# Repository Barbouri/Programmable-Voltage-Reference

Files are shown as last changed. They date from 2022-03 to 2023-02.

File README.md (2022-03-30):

# Programmable-Voltage-Reference
An adjustable 0.001 to 5.000 volt reference, adjustable in 1 mV steps with display
==============================

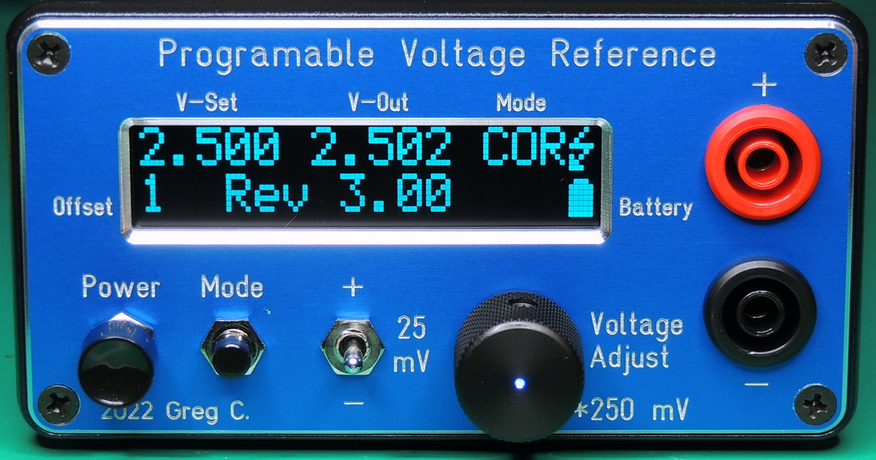
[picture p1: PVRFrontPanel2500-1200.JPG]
Programmable Voltage Reference with 1 mV resolution and 50 uV accuracy

This repository contains the design files and write-up for a Programmable Voltage Reference.  The reference has a range of 1 mV to 5.000 volts in 1 mV steps. The accuracy is plus or minus 50 uV for any set value. The reference value is displayed on a 2 X 16 character OLED display and can be set manually using the rotary encoder or remotely over the TTL serial to isolated USB 2.0 port.

The software folder contains an Arduino / Teensyduino sketch that is the source code for the voltage reference firmware.

Visit https://www.barbouri.com/2022/03/29/updating-the-programmable-voltage-reference-project/ for a more detailed explanation of the project design.

You can order this PCB directly from OSH Park.  Click on the following link.  
  * Programmable Voltage Reference V3.14- https://oshpark.com/shared_projects/pFu2IAUW

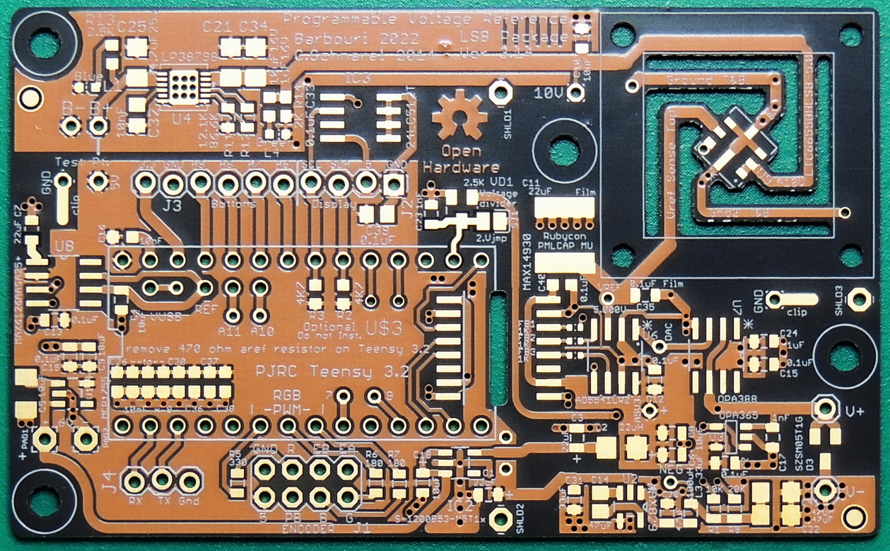
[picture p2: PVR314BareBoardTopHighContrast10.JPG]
PCB Top


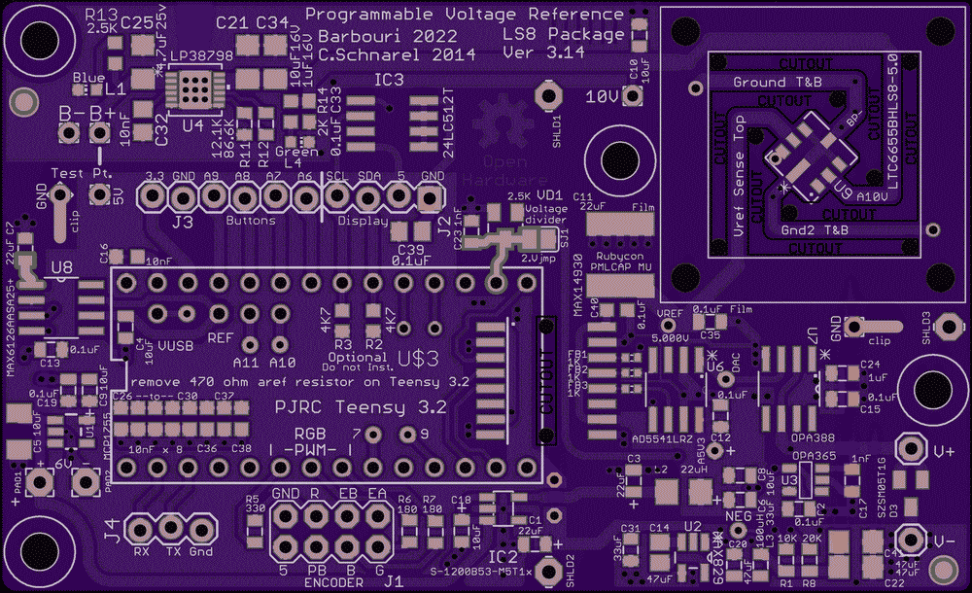
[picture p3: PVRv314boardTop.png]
Design Top


See the Bill of Materials (BOM) file in the repo Hardware folder for a parts list.  

## Status  
  * Version 3.14 PCB has been tested to be functional.
  * Version 3.15 PCB is untested with changes to silkscreen values and circuit trace widths.

## File Formats  

Hardware design files are in "CadSoft EAGLE PCB Design Software 7.7" .brd and .sch formats.  A free version of the software can be downloaded from https://www.autodesk.com/products/eagle/free-download.

The example code is in Arduino / Teensyduino .ino format (text).  A free version of the Arduino software can be downloaded from www.arduino.cc.
Teensyduino software add-on for the Arduino IDE can be downloaded from https://www.pjrc.com/teensy/teensyduino.html

Front panel was fabricated by "Front Panel Express" using "Front Panel Designer". A free version of the software can be downloaded from https://www.frontpanelexpress.com/front-panel-designer/download

## Distribution License  

Original design by C. Schnarel 2014 https://github.com/uChip/VoltageReferenceProgrammable

License:
<br /><span xmlns:dct="http://purl.org/dc/terms/" property="dct:title">Programmable Voltage Reference</span> by <a xmlns:cc="http://creativecommons.org/ns#" href="https://github.com/Barbouri/Programmable-Voltage-Reference" property="cc:attributionName" rel="cc:attributionURL">G. Christenson 2022 / C.Schnarel 2014</a> is licensed under a <a rel="license" href="http://creativecommons.org/licenses/by-sa/4.0/">Creative Commons Attribution-ShareAlike 4.0 International License</a>.

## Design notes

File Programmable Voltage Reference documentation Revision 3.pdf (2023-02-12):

Programmable Voltage Reference Command Set and Calibration for Revision 3.0 firmware

Serial interface set up: The PVR has an USB connector on the Teensy 3.2 that can be used for communication along with a serial communications header that interfaces with an isolated USB interface board. The protocol is standard UART at 115200-8-N-1. That is, 115200 baud, 8 data bits, no parity and one stop bit. All messages to and from the PVR are readable ASCII text. The messages can be sent or received / monitored by a terminal emulator program, however no line editing (backspace, etc.) is supported.

There is a 30 second delay at turn on to allow voltages and the reference to stabilize. The default mode at turn on is Corrected mode using calibration offsets, and an output voltage of 2.500 volts.
When the PVR powers up it sends out the message "Programmable Voltage Reference V3.0" followed by a carriage return character.
Anytime the PVR reference voltage is manually changed using the rotary encoder, button, toggle switch, or command the PVR sends out a serial communications message containing the new Set reference voltage value, Offset value, and measured Output voltage value, followed by a carriage return character.

Message format: All commands sent to the PVR should be in the form "CNNNN<nl>" (do not include the quotes) where:

C is a single character indicating the command to be done. Valid values are '#', '!', 'W', 'R', 'U','N',’C’,’O’. NNNN is four characters defining a decimal number. Each N is a digit character ('0' thru '9').

Together these form a number. The valid range for the number is defined in the context of the command.

<nl> (newline) is a single termination character. Valid values for <nl> are the carriage return character
( 0x0D ) or the linefeed character ( 0x0A ). If your terminal emulator sends both the extra will be ignored.

Command validation: If the message is less than six characters the message will be discarded. Beyond six characters will be ignored. If the message does not begin with one of the defined command characters the message will be discarded. If the message does not end with one of the <nl> characters the message will be discarded.

Note: Validation is NOT done on the N characters. Decimal conversion is done assuming each N is a valid digit character. If non-digit characters are given the decimal value will be generated based on their ASCII value.

Commands:

#: Sets the PVR reference value to NNNN millivolts, plus the internally stored calibration offset. The calibration offset value is displayed in the lower left Offset area of the OLED display. Only the bottom 13 bits of the reference value are used to program the DAC. A value of zero can be set with this command though the PVR may not actually output exactly zero volts. Values greater than 5000 will be treated as 5000. Front panel OLED displays COR for (corrected). The rotary dial LED is blue in this mode, and changes to violet if the output exceeds the error threshold. Default threshold is 5 mV.

!: Sets the PVR reference value to NNNN millivolts, without adding a calibration offset. Only the bottom 13 bits of the reference value are used to program the DAC. A value of zero can be set with this command though the PVR may not actually output exactly zero volts. Values greater than 5000 will be treated as 5000. The front panel OLED displays RAW, and the rotary dial LED is red in this mode.

W: Writes a value to onboard EEPROM memory. The previous set PVR reference value is used as the EEPROM address. The value to be written is created from NNNN. Only the lower 8 bits are used, therefore NNNN should be restricted to the range "0000" to "0255".
W0001<nl> would store an offset of +76.2 uV and W0255 would store an offset of -76.2 uV.

R: Returns the table of calibration offsets as a series of strings. Each string represents one onboard EEPROM memory location starting from zero. (Not Fully Implemented)
What I would like to implement is sending out a serial communications message with the address and offset value, starting at the current reference set value, and then send NNNN sequential address and offset pairs, and remain in the original mode when complete.

U: Sets an immediate global offset value to be used with the current reference value instead of using the offset from the calibration EEPROM memory. Similar to the W command, but isn’t stored in EEPROM, and is lost on reset or loss of power. Front panel OLED displays UOS in this mode and the rotary dial LED is green. The set global offset is displayed in the lower left Offset area of the OLED display.
For example sending U0002<nl> would set a global offset of +152.4 mV. Any changes to the set reference value using the front panel controls would include the global offset.

N: Returns Normal behavior from U command to look up offsets from the calibration memory and clear the global offset. For example sending N0000<nl> would perform the Return to normal behavior.

O: Turns off the OLED display while leaving the PVR and internal reference powered up. A valid # or ! command restores the OLED display. An example of the OLED off command is O0000<nl> .
Valid range for NNNN is 0000 to 5000 and the reference output is set to the value entered.

C: Front panel Calibration mode. Currently not implemented.
The original intent of the C (Calibrate) function is to put the PVR in a mode that allows the use of the front panel switch and rotary encoder to easily change the calibration offset using a connected calibrated meter on the output.

Instead of typing in offsets thru the USB port, the offset would be changed using the +/- 25 mV switch in 76.2 uV increments with real time changes shown on the calibrated meter, entered and stored using the rotary push-button, and then move on to the next setting using the rotary dial.

A nice addition would be to automatically use the last offset setting for the next output setting, and then just press the push-button to save if the output is within cal limits.

Typically the output stays within cal for many steps before needing to be changed, and then it typically only needs to change by one cal step.

Front Panel:

The front panel includes the 2 line by 16 character OLED display. The top line of the display shows the set reference voltage, the measured output voltage, mode, and charging indicator. The lower line of the display shows the calibration or global offset value, firmware revision, and battery status.

The power button turns on and off all power the unit including battery charging.

The mode button currently only resets the mode and set reference voltage to the default state.

The toggle switch increases or decreases the set reference voltage by 25 mV.

The rotary dial / pushbutton / LED, adjusts the set reference voltage up (clockwise) or down (counterclockwise) in 1 mV steps, pressing the dial pushbutton increases the set value by 250 mV per press until 5.000 volts is reached, and then cycles to 0.001 volts, as does the +/- 25 mV switch, and the rotary dial. The dial LED indicates the current mode and an output error condition.

The +/- reference output banana jacks accept both 4mm standard and safety sheathed banana plugs, and use a standard 0.75” spacing between jacks. The set reference output voltage is adjustable between 0.001 to 5.000 volts in 1 mV steps with a maximum output current of 15 mA.

Back Panel:

The back panel includes a 7.5 volt DC input barrel power jack which needs a minimum 5 watt supply.

The isolated micro USB connector is also located on the back panel and requires 5 volt power thru the connector to operate, which is typical for most USB cables.

Firmware:

The firmware was coded in Arduino 1.8.X and Teensyduino 1.56.
There are several variables in the firmware that set the initial defaults which may be changed:
refVal = 2500 | This sets the initial set reference voltage output to 2.500 volts.
errorvoltage = 5.0 | Maximum error difference between set and output voltage in mV.

oled.setBrightness(50) This sets the initial OLED display screen brightness. Range 0 to 255

delay(30000) | Initial 30 second delay on startup, minimum 5 seconds (5000)

Push button and toggle switch default values of 250 mV and 25 mV.

Additional to-do items:

Add Auto-calibration routine for calibration of Teensy ADC read back of actual output voltage.

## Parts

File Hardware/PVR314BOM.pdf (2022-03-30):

Part Value | Device | Package | Description | MFG | PN
C1 | 22uF | CAP_POL0805 | 0805-POL | Capacitor 22µF Molded Tantalum Polymer 10V 0805 200mOhm | KYOCERA AVX | F381A226MSA
C2 | 0.1uF | CAP0805 | 0805 | Capacitor ceramic bypass
C3 | 22uF | CAP_POL0805 | 0805-POL | Capacitor 22µF Molded Tantalum Polymer 10V 0805 200mOhm | KYOCERA AVX | F381A226MSA
C4 | 10uF | CAP0805 | 0805 | Capacitor
C5 | 10uF | CAP1206 | C1206K | Capacitor 10µF ±10% 16V Ceramic X7R 1206 | Kemet | C1206X105K4RACAUTO
C6 | 33uF | CAP_POL0805 | 0805-POL | Capacitor 33µF Molded Tantalum Polymer 10V 0805 200mOhm | KYOCERA AVX | F381A336MSALZT
C7 | 22uF | CAP0805 | 0805 | Capacitor
C8 | 10uF | CAP0805 | 0805 | Capacitor
C9 | 10uF | CAP_POL0805 | 0805-POL | Capacitor 10µF Molded Tantalum Polymer 10V 0805 200mOhm | KEMET | T529P106M010AAE200
C10 10uF | CAP0805 | 0805 | Capacitor
C11 22uF | CAP2220 | C2220K | Capacitor Film 22uF 20% 16VDC 2220 | Rubycon | 16MU226MD35750
C12 0.1uF | CAP0805 | 0805 | Capacitor ceramic bypass
C13 0.1uF | CAP0805 | 0805 | Capacitor ceramic bypass
C14 47uF | CAP0805 | C0805 | Capacitor 47µF ±20% 10V Ceramic X5R 0805 | KYOCERA AVX | 0805ZD476MAT2A
C15 0.1uF | CAP0805 | 0805 | Capacitor ceramic bypass
C16 10nF | CAP0603 | C0603K | Capacitor ceramic bypass
C17 1nF | CAP0805 | 0805 | Capacitor ceramic bypass C0G
C18 10uF | CAP_POL0805 | 0805-POL | Capacitor 10µF Molded Tantalum Polymer 10V 0805 200mOhm | KEMET | T529P106M010AAE200
C19 0.1uF | CAP0805 | 0805 | Capacitor ceramic bypass
C20 47uF | CAP0805 | 0805 | Capacitor
C21 10uF16V | CAP1206 | C1206 | Capacitor 10 µF ±10% 16V Ceramic X7R 1206 | Kemet | C1206X106K4RACAUTO
C22 47uF | CAPPOL1206 | 1206 | Capacitor Tantalum Polymer 6.3 V 1206 45mOhm | Vishay Spraque | T55A107M6R3C0045
C23 1nF | CAP0805 | 0805 | Capacitor
C24 1uF | CAP0805 | 0805 | Capacitor
C25 4.7uF25v | CAP1206 | C1206 | Capacitor
C26 10nF | CAP0603 | C0603K | Capacitor ceramic bypass
C27 10nF | CAP0603 | C0603K | Capacitor ceramic bypass
C28 10nF | CAP0603 | C0603K | Capacitor ceramic bypass
C29 10nF | CAP0603 | C0603K | Capacitor ceramic bypass
C30 10nF x 8 | CAP0603 | C0603K | Capacitor ceramic bypass
C31 33uF | CAP0805 | 0805 | Capacitor 33 µF Molded Tantalum Polymer 10V 0805 200mOhm | KYOCERA AVX | F381A336MSALZT
C32 10nF | CAP0805 | C0805 | Capacitor ceramic bypass
C33 0.1uF | CAP0603 | C0603 | Capacitor ceramic bypass

C34 1uF16V | CAP1206 | C1206 | Capacitor 1 µF ±10% 16V Ceramic X7R 1206 | Kemet | C1206X105K4RACAUTO
C35 0.1uF Film | CAP0805 | 0805 | Capacitor Film 0.1uF 20% 16VDC 2220 | Rubycon | 25MU104KZ22012
C36 10nF | CAP0603 | C0603K | Capacitor ceramic bypass
C37 10nF | CAP0603 | C0603K | Capacitor ceramic bypass
C38 10nF | CAP0603 | C0603K | Capacitor ceramic bypass
C39 0.1uF | CAP0805 | C0805 | Capacitor ceramic bypass
C40 0.1uF | CAP0603 | C0603 | Capacitor ceramic bypass
C41 47uF | CAPPOL1206 | 1206 | Capacitor Tantalum Polymer 6.3 V 1206 45mOhm | Vishay Spraque | T55A107M6R3C0045
D3 | SZSM05T1G | DIODE_CA-AC__ | SOT23C | 5V RS 9.8V Clamp 17A Ipp Tvs Diode Surface Mount SOT-23-3 | On Semiconductor | SZSM05T1G
FB1 1K | Ferrite Bead Inductor 0402 | Ferrite Bead Inductor 1 kOhms @ 100 MHz SMD 0402 | Murata | BLM15HG102SH1D
FB2 1K | Ferrite Bead Inductor 0402 | Ferrite Bead Inductor 1 kOhms @ 100 MHz SMD 0402 | Murata | BLM15HG102SH1D
FB3 1K | Ferrite Bead Inductor 0402 | Ferrite Bead Inductor 1 kOhms @ 100 MHz SMD 0402 | Murata | BLM15HG102SH1D
IC1 | MAX14930 | ISO7240 | SO-16DW | Digital Isolator 2750Vrms 4 Channel 25Mbps 16-SOIC-Wide | Analog Devices Inc./Maxim | MAX14930EAWE+
IC2 | S-1200B53-M5T1x MIC5219XX | SOT23-5 | IC REG LINEAR 5.3V 150MA SOT23-5 | ABLIC Inc. | S-1200B53-M5T1U
IC3 | 24LC64SN | SO8-EEPROM | SO-08 | Serial EEPROM 64/128/256/or 512K | MICROCHIP | 24LC64-I/SN
J1 | Encoder | M04X2 | 2X4 | 0.1" spacing Header, two rows of four | TE Connectivity AMP Connectors | 826656-4
J2 | Display | M04X1 | 1X04_LOCK | 0.1" spacing Header 4 part of 1X16 piece | TE Connectivity AMP Connectors | 1-825433-6
J3 | Buttons | M06X1 | 1X06_LOCK | 0.1" spacing Header 6 part of 1X16 piece | TE Connectivity AMP Connectors
J4 | Serial | M03X1 | 1X03_LOCK | 0.1" spacing Header 3 part of 1X16 piece | TE Connectivity AMP Connectors
H1T Teensy-R | M14X1 | 1X14 | Connector Header Through Hole 14 position 0.100" series 350 | Mill-Max Manufacturing Corp. | 350-10-114-00-006000
H1B Teensy-R | F14X1 | 1X14 | Connector Header Through Hole 14 position 0.100" series 350 | Mill-Max Manufacturing Corp. | 310-41-114-41-001000
H2T Teensy-L | M14X1 | 1X14 | Connector Header Through Hole 14 position 0.100" series 350 | Mill-Max Manufacturing Corp. | 350-10-114-00-006000
H2B Teensy-L | F14X1 | 1X14 | Connector Header Through Hole 14 position 0.100" series 350 | Mill-Max Manufacturing Corp. | 310-41-114-41-001000
H3T Teensy-I | M05X1 | 1X5 -1 | Connector Header Through Hole 5 position 0.100" Remove 1 pos | Mill-Max Manufacturing Corp. | 350-10-105-00-006000
H3B Teensy-I | F05X1 | 1X5 -1 | Connector Header Through Hole 5 position 0.100" Remove 1 pos | Mill-Max Manufacturing Corp. | 310-41-105-41-001000
L1 | Blue | 0603-LED | 0603 | LED Blue 0603 | Kingbright | APHM1608VRBXF/A-5
L2 | 22uH | 1210-IND | 1210 | INDUCTOR 22µH Shielded Wirewound 120mA 480mOhm Max | TDK Corporation | NLFV32T-220K-EF
L3 | 100uH | 0805-IND | 0805 | Inductors 100UH 50MA 4 OHM SMD | Taiyo Yuden | LBR2012T101KV
L4 | Green | 0603-LED | 0603 | LED Green 0603 | Vishay Semiconductor | VLMTG1300-GS08
R1 | 10K | 0805-RES | 0805 | Resistor 1% to 5%
R2 | 4.7K | 0603-RES | 0603 | Resistor Optional for testing - Do Not Install
R3 | 4.7K | 0603-RES | 0603 | Resistor Optional for testing - Do Not Install
R5 | 330 | 0805-RES | 0805 | Resistor 1% to 5%
R6 | 180 | 0805-RES | 0805 | Resistor 1% to 5%

R7 | 180 | 0805-RES | 0805 | Resistor 1% to 5%
R8 | 20K | 0805-RES | 0805 | Resistor 1% to 5%
R11 12.1K | 0805-RES | 0805 | Resistor ±0.1% 0.125W, 1/8W | Vishay Dale | TNPW080512K1BEEA
R12 86.6K | 0805-RES | 0805 | Resistor ±0.1% 0.125W, 1/8W | Vishay Dale | TNPW080580K6BEEN
R13 2.5K | 0603-RES | 0603 | Resistor 1% to 5%
R14 2K | 0603-RES | 0603 | Resistor 1% to 5%
U$3 PJRC Teensy 3.2 | TEENSY_3.1_DIL+4 | TEENSY-DIL+4 Teensy 3.1 and 3.2 in a DIL package with the inner 4 pins
U1 | MCP1755 | V_REG_LDOSMD | SOT-23-5 | IC REG LINEAR 5V 300MA SOT23-5 LDO | Microchip Technology | MCP1755T-5002E/OT
U2 | MAX829 | MAX829EUK+T | SOT-23-5 | Switched-Capacitor Voltage Inverters | Maxim | MAX829EUK+T
U3 | OPA365 | OPA365 | SOT-23-5 | General Purpose Amplifier 1 Circuit Rail-to-Rail SOT-23-5 | Texas Instruments | OPA365AIDBVR
U4 | LP38798 | LP38798SD-ADJ | DNT12 | | Texas Instruments | LP38798SD-ADJ/NOPB
U6 | AD5541LRZ | AD5541LRZ | SOIC-8 | 16-Bit Digital-to-Analog Converters | Analog Devices | AD5541LRZ
U7 | OPA388 | LTC2050IS8PBF | SOIC-8 | Zero-Drift Operational Amplifi ers | Linear Technology | OPA388
U8 | MAX6126AASA25+ Voltage Reference | SOIC-8 | Series, Buried Zener Reference. Fixed 2.5V 0.04% 15mA 8-SOIC | Analog Devices Inc./Maxim | MAX6225ACSA+
U9 | LTC6655BHLS8-5.0 Voltage Reference | LCC-8_LS8 | Series Voltage Ref. IC Fixed 5V 0.025% 5 mA 8-CLCC | Linear Technology | LTC6655BHLS8-5.000
VD1 2.5K-2.5K | LM50 | SOT-23 | SOT-23 Voltage Divider

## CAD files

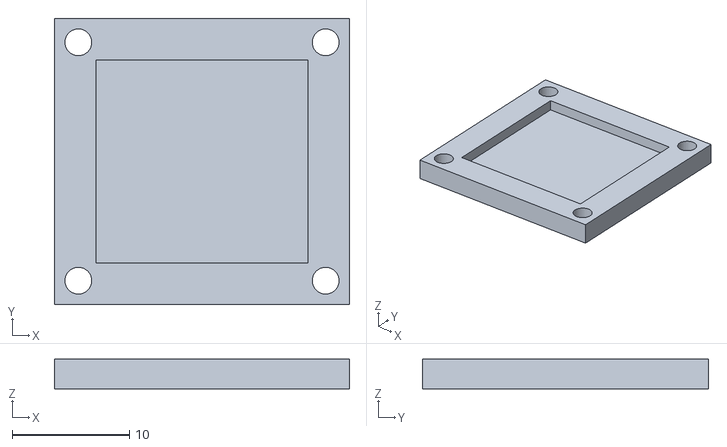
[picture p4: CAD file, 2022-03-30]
Hardware/3DcoversSTL/Bottom_Cover1_v1.stl
25.1 x 24.4 x 2.54

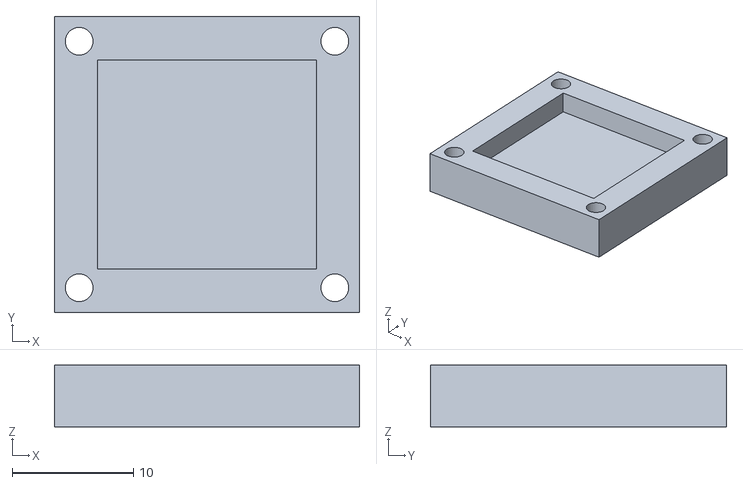
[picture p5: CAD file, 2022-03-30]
Hardware/3DcoversSTL/Top_Cover1_v1.stl
25.1 x 24.4 x 5.08

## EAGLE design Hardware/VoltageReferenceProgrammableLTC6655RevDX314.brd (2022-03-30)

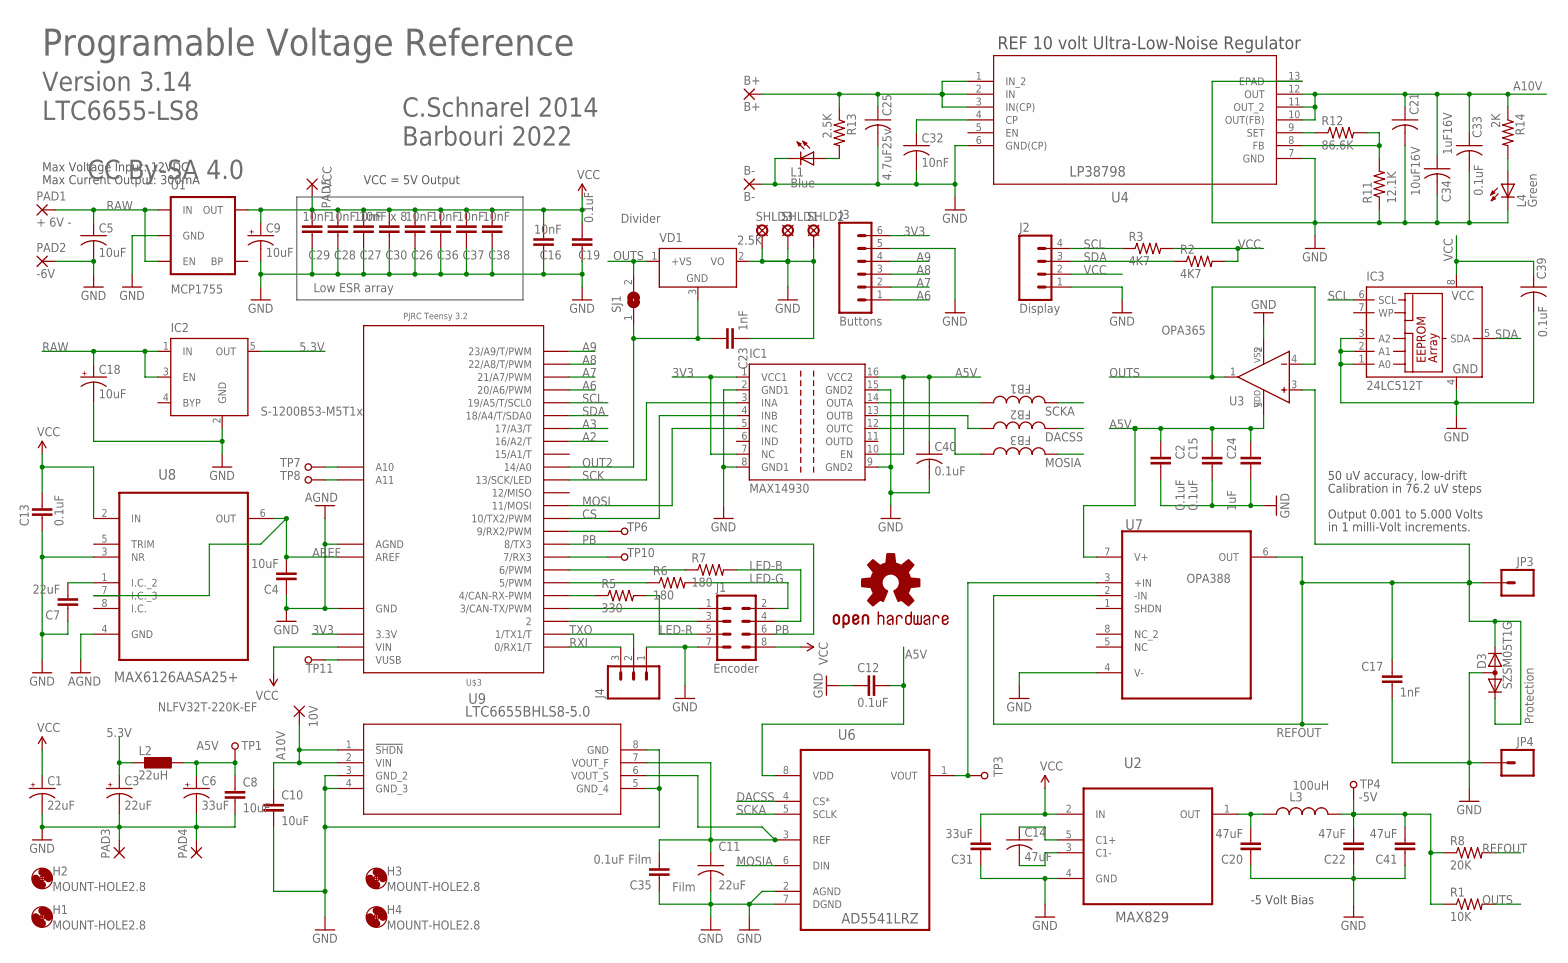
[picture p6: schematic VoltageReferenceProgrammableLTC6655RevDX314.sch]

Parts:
10V: 1,6/0,9
B+: B+; 1,6/0,9
B-: B-; 1,6/0,9
C1, C3: 22uF; 0805-POL
C2, C12, C13, C15, C19: 0.1uF; 0805
C4, C8, C10: 10uF; 0805
C5: 10uF; C1206K
C6: 33uF; 0805-POL
C7: 22uF; 0805
C9, C18: 10uF; 0805-POL
C11: 22uF; C2220K
C14: 47uF; C0805
C16, C26, C27, C28, C29, C36, C37, C38: 10nF; C0603K
C17, C23: 1nF; 0805
C20: 47uF; 0805
C21: 10uF16V; C1206
C22, C41: 47uF; 1206
C24: 1uF; 0805
C25: 4.7uF25v; C1206
C30: 10nF x 8; C0603K
C31: 33uF; 0805
C32: 10nF; C0805
C33, C40: 0.1uF; C0603
C34: 1uF16V; C1206
C35: 0.1uF Film; 0805
C39: 0.1uF; C0805
D3: SZSM05T1G; SOT23C
FB1, FB2, FB3: 1K; WE-CBA_0402(W=1.5)
H1, H2, H3, H4: MOUNT-HOLE2.8; 2,8
IC1: MAX14930; SO-16DW
IC2: S-1200B53-M5T1x; SOT23-5
IC3: 24LC512T; SO-08
J1: Encoder; 2X4
J2: Display; 1X04_LOCK
J3: Buttons; 1X06_LOCK
J4: M03LOCK; 1X03_LOCK
JP3, JP4: M01PTH; 1X01
L1: Blue; CHIP-LED0603
L2: 22uH; L3225P
L3: 100uH; 0805
L4: Green; CHIP-LED0603
LOGO1: OSHW-LOGOM; OSHW-LOGO-M
PAD1: + 6V -; 2,15/1,0
PAD2: -6V; 2,15/1,0
PAD3, PAD4, PAD5: 1,6/0,9
R1: 10K; 0805
R2, R3: 4K7; R0603
R5: 330; 0805
R6, R7: 180; 0805
R8: 20K; 0805
R11: 12.1K; 0805
R12: 86.6K; 0805
R13: 2.5K; R0603
R14: 2K; R0603
SHLD1, SHLD3: SHLD1; LSP11
SHLD2: SHLD2; LSP11
SJ1: SJ
TP1, TP3, TP4, TP6, TP7, TP8, TP10, TP11: TEST_POINT; BBD-VIA
U1: MCP1755; SOT23-5
U2: MAX829; SOT95P280X145-5N
U3: OPA365; SOT-23-5
U4: LP38798; DNT12
U6: AD5541LRZ; SOIC127P600X175-8N
U7: OPA388; SOIC127P600X175-8N; MPN OPA388
U8: MAX6126AASA25+; SOIC127P600X175-8N
U9: LTC6655BHLS8-5.0; LCC-8_LS8
U$3: PJRC Teensy 3.2; TEENSY3-DIL+4
VD1: 2.5K; SOT23

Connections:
3V3: IC1.1 (VCC1), IC1.7 (NC), J3.6, U$3.3.3V
5.3V: C3.1 (+), IC2.5 (OUT), L2.2
9: TP6.P$1, U$3.9 (9/RX2/PWM)
-5V: C22.2, C41.2, L3.2, R1.1, R8.1, TP4.P$1
A2: U$3.16/A2 (16/A2/T)
A3: U$3.17/A3 (17/A3/T)
A5V: C2.1, C6.1 (+), C8.1, C12.1, C15.1, C24.1, C40.1, IC1.10 (EN), IC1.16 (VCC2), L2.1, TP1.P$1, U3.5 (VDD), U6.8 (VDD), U7.7 (V+)
A6: J3.1, U$3.20/A6 (20/A6/PWM)
A7: J3.2, U$3.21/A7 (21/A7/PWM)
A8: J3.3, U$3.22/A8 (22/A8/T/PWM)
A9: J3.4, U$3.23/A9 (23/A9/T/PWM)
A10V: 10V.1, C10.1, C21.1, C33.1, C34.1, R14.1, U4.10 (OUT(FB)), U4.11 (OUT_2), U4.12 (OUT), U9.1 (!SHDN), U9.2 (VIN)
AGND: U8.4 (GND)
AREF: C4.2, U8.6 (OUT), U8.7 (I.C._3), U$3.AREF
BATT: B+.1, C25.1, R13.1, U4.1 (IN_2), U4.2 (IN), U4.3 (IN(CP))
CS: IC1.4 (INB), U$3.10 (10/TX2/PWM)
DACSS: FB2.2, U6.4 (CS*)
EA: J1.1, U$3.3 (3/CAN-TX/PWM)
EB: J1.3, U$3.2
GND: B-.1, C1.2 (-), C2.2, C3.2 (-), C4.1, C5.2, C6.2 (-), C7.1, C8.2, C9.2 (-), C10.2, C11.2, C12.2, C13.2, C15.2, C16.1, C17.1, C18.2 (-), C19.1, C20.1, C21.2, C22.1, C23.1, C24.2, C25.2, C26.1, C27.1, C28.1, C29.1, C30.1, C31.1, C32.2, C33.2, C34.2, C35.1, C36.1, C37.1, C38.1, C39.2, C40.2, C41.1, D3.3 (A), IC1.2 (GND1), IC1.8 (GND1), IC1.9 (GND2), IC1.15 (GND2), IC2.2 (GND), IC3.1 (A0), IC3.2 (A1), IC3.3 (A2), IC3.4 (GND), J1.7, J2.1, J3.5, J4.1, JP4.1, L1.C, L4.C, PAD2.1, PAD3.1, PAD4.1, R11.1, SHLD1.MP, SHLD2.MP, SHLD3.MP, U1.2 (GND), U2.4 (GND), U3.2 (VSS), U4.6 (GND(CP)), U4.7 (GND), U4.13 (EPAD), U6.2 (AGND), U6.7 (DGND), U7.4 (V-), U8.3 (NR), U9.3 (GND_2), U9.4 (GND_3), U9.5 (GND_4), U9.8 (GND), U$3.AGND, U$3.GND, VD1.2 (VO)
LED-B: J1.4, R7.2
LED-G: J1.2, R6.2
LED-R: J1.5, R5.2
MOSI: IC1.5 (INC), U$3.11 (11/MOSI)
MOSIA: FB3.2, U6.6 (DIN)
unnamed: R12.1, U4.9 (SET)
unnamed: C7.2, U8.1 (I.C._2)
unnamed: R5.1, U$3.4 (4/CAN-RX-PWM)
unnamed: R6.1, U$3.5 (5/PWM)
unnamed: R7.1, U$3.6 (6/PWM)
unnamed: TP3.P$1, U6.1 (VOUT), U7.3 (+IN)
unnamed: TP7.P$1, U$3.A10
unnamed: C20.2, L3.1, U2.1 (OUT)
unnamed: TP8.P$1, U$3.A11
unnamed: R11.2, R12.2, U4.8 (FB)
unnamed: TP10.P$1, U$3.7 (7/RX3)
unnamed: TP11.P$1, U$3.VUSB
unnamed: C14.2, U2.3 (C1-)
unnamed: C32.1, U4.4 (CP)
unnamed: C14.1, U2.5 (C1+)
unnamed: FB1.1, IC1.14 (OUTA)
unnamed: L1.A, R13.2
unnamed: FB2.1, IC1.13 (OUTB)
unnamed: FB3.1, IC1.12 (OUTC)
unnamed: L4.A, R14.2
OUT2: C23.2, SJ1.1, U$3.14/A0, VD1.3 (GND)
OUTS: R1.2, SJ1.2, U3.1 (OUT), U3.4 (IN-), VD1.1 (+VS)
PB: J1.6, U$3.8 (8/TX3)
RAW: C5.1, C18.1 (+), IC2.1 (IN), IC2.3 (EN), PAD1.1, U1.1 (IN), U1.3 (EN)
REFOUT: C17.2, D3.1 (K1), D3.2 (K2), JP3.1, R8.2, U3.3 (IN+), U7.2 (-IN), U7.6 (OUT)
RXI: J4.3, U$3.0 (0/RX1/T)
SCK: IC1.3 (INA), U$3.13 (13/SCK/LED)
SCKA: FB1.2, U6.5 (SCLK)
SCL: IC3.6 (SCL), J2.4, R3.1, U$3.19/A5 (19/A5/T/SCL0)
SDA: IC3.5 (SDA), J2.3, R2.1, U$3.18/A4 (18/A4/T/SDA0)
TXO: J4.2, U$3.1 (1/TX1/T)
VCC: C1.1 (+), C9.1 (+), C13.1, C16.2, C19.2, C26.2, C27.2, C28.2, C29.2, C30.2, C31.2, C36.2, C37.2, C38.2, C39.1, IC3.8 (VCC), J1.8, J2.2, PAD5.1, R2.2, R3.2, U1.5 (OUT), U2.2 (IN), U8.2 (IN), U$3.VIN
VREF: C11.1, C35.2, U6.3 (REF), U9.6 (VOUT_S), U9.7 (VOUT_F)

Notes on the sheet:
Max Voltage Input: 12VDC
Max Current Output: 300mA
VCC = 5V Output
Programable Voltage Reference
Version 3.14 LTC6655-LS8
Output 0.001 to 5.000 Volts
in 1 milli-Volt increments.
50 uV accuracy, low-drift
Calibration in 76.2 uV steps
C.Schnarel 2014 Barbouri 2022
Protection
Divider
Low ESR array
CC By-SA 4.0
REF 10 volt Ultra-Low-Noise Regulator
-5 Volt Bias

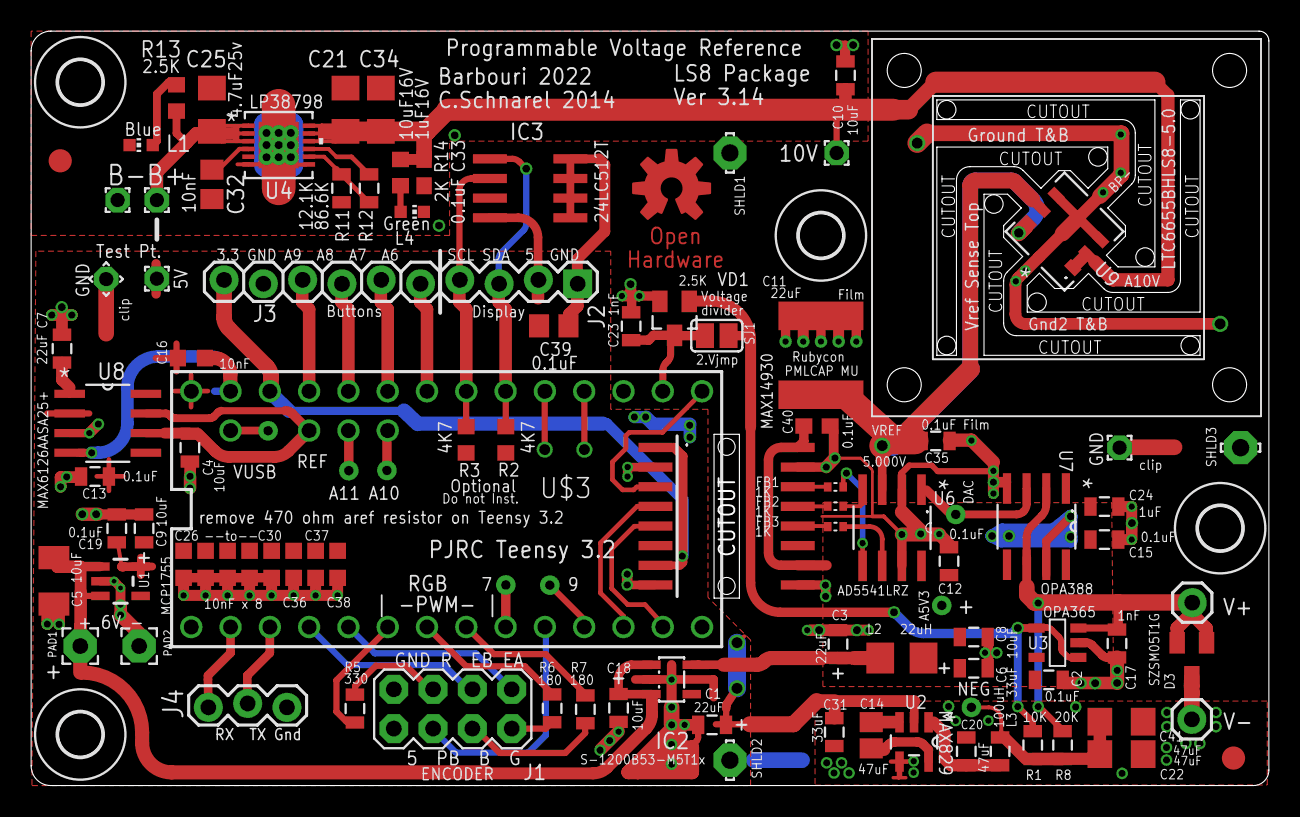
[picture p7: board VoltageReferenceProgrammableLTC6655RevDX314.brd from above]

Board: 2 copper layers, 80.0 x 48.8 mm, 107 parts (1 on the bottom side), 55 nets.

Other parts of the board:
FID1: 1; FIDUCIAL_G15
FID2: 2; FIDUCIAL_G15
U$1: OSHW-LOGO-M_COPPER

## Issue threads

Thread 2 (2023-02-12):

Feature - Add Auto-calibration routine for Teensy ADC

Barbouri, 2023-02-12:
Add Auto-calibration routine for calibration of Teensy ADC read back of actual output voltage.
Assign command code "A" and require confirmation to proceed using Mode button.

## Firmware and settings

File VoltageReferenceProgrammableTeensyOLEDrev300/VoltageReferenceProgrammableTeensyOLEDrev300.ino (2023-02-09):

/* Programmable Voltage Reference V3.00
For use with Barbouri - Programmable Voltage Reference V3.15 - V3.16 circuit boards
2014 uChip (C. Schnarel) Original software for RevD boards
2017 Barbouri (G. Christenson) Modified for Teensy 3.2 based board with I2C LED display
http://www.barbouri.com/2016/07/21/programmable-voltage-reference-v2-12-assembly/
CC BY-SA 4.0 US
12 September 2017 added +/-50mv buttons on pins 21, 22
   added Mode reset switch on pin 20 for CORRECTED mode and 1.000V
   added Power switch on pin 23 to disable LTC1152 and place it in tri-state mode,
   clear LED display (blank), and set LEDcolor to black. Teensy and references
   remain powered. After switching power switch on, Mode reset must be pressed.
   added averaging for Teensy A0 input voltage monitoring, and additional calibration
   variables to compensate for Teensy A-D errors

Modified for V2.25 board - LTC1152 enable, onboard -5 supply, serial & button headers

January 2022 - major update for hardware version 3.14/3.15 5.000 volt PVR
  see blog post for more information - https://www.barbouri.com/2022/03/29/updating-the-programmable-voltage-reference-project/
  
Include libraries this sketch will use
*/
#include <SPI.h>                  // part of Arduino - Teensyduino distribution
#include <EEPROM.h>               // part of Arduino - Teensyduino distribution
#include <JC_EEPROM.h>            // https://github.com/JChristensen/JC_EEPROM
#include <Rotary.h>               // https://github.com/brianlow/Rotary
#include <Bounce2.h>              // http://playground.arduino.cc/Code/Bounce
#include <Wire.h>                 // part of Arduino - Teensyduino distribution
#include <avr/io.h>
#include <avr/interrupt.h>        // AVR interrupt header
#include "I2cCharDisplay.h"       // https://github.com/dcityorg/i2c-char-display-library-arduino
#include <Adafruit_MCP23017.h>    // Adafruit IO expander wothout display
// #include <Adafruit_RGBLCDShield.h>   // include MODIFIED Adafruit RGB I2C Display to include 6th MENU button
// #include "Adafruit_LEDBackpack.h" // https://github.com/adafruit/Adafruit_LED_Backpack
// #include "Adafruit_GFX.h"         // https://github.com/adafruit/Adafruit-GFX-Library

// Defines
#define OLEDADDRESS    0x3c       // i2c address for the oled display
I2cCharDisplay oled(OLED_TYPE, OLEDADDRESS, 2); // create an oled object for a 2 line display

// Create a set of new symbols that can be displayed on the LCD
byte batt_full[8] = {B01110,B11111,B11111,B11111,B11111,B11111,B11111,B11111};      // full battery, 9.0V
byte batt_8_7[8] = {B00000,B01110,B11111,B11111,B11111,B11111,B11111,B11111};       // 8.7V level
byte batt_8_3[8] = {B00000,B00000,B01110,B11111,B11111,B11111,B11111,B11111};       // 8.3V level
byte batt_8_0[8] = {B00000,B00000,B00000,B01110,B11111,B11111,B11111,B11111};       // 8.0V level
byte batt_7_7[8] = {B00000,B00000,B00000,B00000,B01110,B11111,B11111,B11111};       // 7.7V level
byte batt_7_5[8] = {B00000,B00000,B00000,B00000,B00000,B01110,B11111,B11111};       // 7.5V level
byte batt_empty[8] = {B00100,B00100,B00100,B00000,B00100,B00000,B01110,B11111};     // <7.3V Empty
byte batt_charging[8] = {B00010,B00100,B01000,B11111,B00010,B10100,B11000,B11100};  // >10V Charging symbol

// DAC Slave Select
#define DACSS 10

// Mode values
#define CORRECTED true  // send refVal to DAC after adding correction factor
#define RAW false       // send raw refVal numbers to the DAC w/o correcting

// RGB Rotary encoder LED's
#define redled 4
#define greenled 5
#define blueled 6

// LTC1152 enable output to MAX14930 isolator pin 6 input, pin 11 output to LTC1152
#define outputena 9

// Instantiate Rotary encoder object
Rotary r = Rotary(2, 3);
// Instantiate Bounce objects
Bounce bp = Bounce();
Bounce bu = Bounce();
Bounce bd = Bounce();
Bounce bm = Bounce();

// Setup JC_EEPROM values for 24LC512T IC1
JC_EEPROM eep(JC_EEPROM::kbits_512, 2, 64);      //one 24LC512 EEPROM on the bus - device size, number of devices, page size
  
// Instantiate objects used in this project
int16_t MAXVAL = 5000;    // DAC Maximum value
int16_t MINVAL = 1;        // DAC Minimum value

// LED colors used in LEDcolor()
uint8_t red = 0x1;
uint8_t yellow = 0x3;
uint8_t green = 0x2;
uint8_t teal = 0x6;
uint8_t blue = 0x4;
uint8_t violet = 0x5;
uint8_t white = 0x7;
uint8_t black = 0x0;

int DispBCD = 0;
int analog0 = A0;           // Analog input pin on Teensy 3.2
int code = 0;
int color = 0;
uint32_t i = 0;
int8_t offset = 0;
int16_t refVal = 2500;      // Initial voltage output setting 2.500 volt
float num = refVal;
uint32_t Addr = 0;
uint8_t CmdArray[7];
uint8_t CmdArrayIdx = 0;
uint8_t sdata;
uint16_t DACreg;
boolean newVal = true;
boolean mode = CORRECTED;   // when mode = CORRECTED then offset value is used
boolean useFlag = false;    // when true uses downloaded value of offset
// boolean PWR = true;         // Power switch
float errorvoltage = 5.0;   // Maximum difference between set and output voltage
float average = 0.0000;     // the average for A0 read


//-=|=-=|=-=|=-=|=-=|=-=|=-=|=-=|=-=|=-=|=-=|=-=|=-=|=-=|=-=|=-=|
void setup() {
  // Initialize USB interface
  Serial1.begin(115200);
  r.begin(false);
  delay(250);
  Serial1.println("Programmable Voltage Reference V3.00");

  oled.begin();             // initialize the oled

  // Load battery symbols to OLED memory
    oled.createCharacter(0, batt_full);
    oled.createCharacter(1, batt_8_7);
    oled.createCharacter(2, batt_8_3);
    oled.createCharacter(3, batt_8_0);
    oled.createCharacter(4, batt_7_7);
    oled.createCharacter(5, batt_7_5);
    oled.createCharacter(6, batt_empty);
    oled.createCharacter(7, batt_charging);

  // Setup initial OLED display screen
    oled.setBrightness(50);
    oled.clear();
    oled.cursorMove(1, 1);
    oled.print("0.000 0.000 COR");
    oled.cursorMove(1, 16);
    oled.write(7);
    oled.cursorMove(2, 16);
    oled.write(1);
    oled.cursorMove(2, 1);
    oled.print("Rev 3.0 Delay30");
  delay(30000);
    oled.cursorMove(2, 1);
    oled.print("   Rev 3.00    ");
    
  //---- initialize the i2c/MCP23017 library
  Adafruit_MCP23017 mcp;
 
  pinMode(redled, OUTPUT);
  pinMode(greenled, OUTPUT);
  pinMode(blueled, OUTPUT);
  pinMode(outputena, OUTPUT);
  digitalWrite(outputena, HIGH);
  
  LEDcolor(blue);           // Set initial LED color
  mcp.begin();      // use default address 0
  // lcd.setBacklight(BLUE);   // set I2C RGB LED color to Blue

  byte i2cStat = eep.begin(JC_EEPROM::twiClock400kHz);
    if ( i2cStat != 0 ) {
      Serial1.print ("EEPROM setup problem");  //there was a problem
    }

  // Initialize EEPROM to 0's *****************************
  // Run once to set all MAXVAL memory values to 0 by uncommenting
  // the next three lines, and running once on the Teensy 3.2, then recomment.
  // for(i=0;i<MAXVAL;i++){
  //     eep.write(i, 0);  
  //   }

  // Calibrate Teensy ADC to Output value
  // for(i=6000;i<11000;i++){
  //     eep.write(i, 0);  
  //   }

  // Attach buttons with de-bounce using "Bounce2"
  bp.attach(8, INPUT);
  bp.interval(5);
  bu.attach(22,INPUT_PULLUP);
  bu.interval(5);
  bd.attach(21, INPUT_PULLUP);
  bd.interval(5);
  bm.attach(23, INPUT_PULLUP);
  bm.interval(5);
  
  bp.update();          // Check if Rotary encoder button is held On, on power-up
  if(bp.read() == HIGH) {
    mode = RAW;             // If button is held-On set RAW mode
    LEDcolor(red);
    }
    else {
    mode = CORRECTED;       // If button is Off set normal CORRECTED mode
    LEDcolor(blue);
    }
 
  // Setup A-D converter on Teensy 3.2 to use external 2.048 reference and 14 bits
  analogReference(EXTERNAL);
  analogReadResolution(14);
  analogReadAveraging(32);
  
  // set up the select control pin for the DAC
  // DAC select is active low, data is shifted in MSB first
  // on the falling edge of the clock
  pinMode(DACSS, OUTPUT);
  digitalWrite(DACSS, HIGH);
  SPI.begin();
  SPI.setDataMode(SPI_MODE1);  // set to falling edge clock
  SPI.setBitOrder(MSBFIRST);  // set to MSB first
}

// =-=|=-=|=-=|=-=|=-=|=-=|=-=|=-=|=-=|=-=|=-=|=-=|=-=|=-=|=-=|=-=|
void loop() {
  
  // Increment by 500 if the rotary encoder button was pressed
  // If the increment result is more than MAX just set result to zero
  if(bp.update()) {
    if(bp.read() == HIGH) {
      refVal+=250;
      if(refVal>MAXVAL)refVal=1;
      newVal = true;
    }
  }

  // Increment by 50 if the panel 50mv + button was pressed
  // If the increment result is more than MAX just set result to zero
  if(bu.update()) {
    if(bu.read() == HIGH) {
      refVal+=25;
      if(refVal>MAXVAL)refVal=1;
      newVal = true;
    }
  }
  
  // Decrement by 50 if the panel 50mv - button was pressed
  // If the decrement result is less than MIN just set result to zero
  if(bd.update()) {
    if(bd.read() == HIGH) {
      refVal-=25;
      if(refVal<MINVAL)refVal=1;
      newVal = true;
    }
  }

  // Reset to CORRECTED mode if the panel Mode - button was pressed
  // Set Output to 1.000 V and enable LTC1152 output
  
  if(bm.update()) {
    if(bm.read() == HIGH) {
    mode = CORRECTED;
    LEDcolor(blue);
    refVal = 2500;
    newVal = true;
    }
  }

  // Check the rotary encoder and increment or decrement if it was turned
  // If the increment result is more than MAX roll over to zero
  // If the decrement goes below zero value will roll over to 65535 (unsigned word)
  // In that case set to result to MAX value
  unsigned char result = r.process();
  if (result) {
    result == DIR_CW ? refVal-- : refVal++;
    if(refVal<1)refVal=MAXVAL;
    if(refVal>MAXVAL)refVal=1;
    newVal = true;
  }

  while (Serial1.available())  // Read command from Teensy USB connection
                              // requires mode character, 4 numeric digits, then
                              // LineFeed or CarrigeReturn or both
                              // valid mode charactors: # ! W R U N O C
  {
    sdata = Serial1.read();
    switch (sdata){
    case 35: // '#'  set DAC with correction factor
    case 33: // '!'  set DAC with no correction factor
    case 'W': // 'W' write offset values to EEPROM
    case 'R': // 'R' dump the offset table (mostly for debug)
    case 'U': // 'U' use a temporary offset (must be in CORRECTED mode to use)
    case 'N': // 'N' clear temporary offset and use correction factor
    case 'O': // 'O' turn Off OLED and set DAC with correction factor
    case 'C': // 'C' set calibration mode with no correction factor
      CmdArrayIdx = 0;
      CmdArray[CmdArrayIdx++] = sdata;
      break;
    case 10: // LF
    case 13: // CR
      CmdArray[CmdArrayIdx++] = sdata;
      if(ParseCommand())
        newVal = true;
      break;
    default:
      CmdArray[CmdArrayIdx++] = sdata;
      if(CmdArrayIdx>6) CmdArrayIdx = 6;
    }
  }  

  // If the value has changed, update the display and send 
  // the new value to the DAC and the serial port
  if(newVal) {
    Serial1.print("Set voltage = ");
    Serial1.print((float)refVal/1000, 3);
        
    // Convert the 12-bit DAC value into a 16-bit value plus
    // an optional signed 8-bit correction factor.
    
    // First look up the correction factor
    if(!useFlag){
      offset = eep.read(refVal);
    }
    
    // Next shift the 12-bit value up 4 bits and add in the correction factor if desired.
    if(mode == CORRECTED) {
     Serial1.print(" Offset = ");
     Serial1.print(offset);
     oled.cursorMove(2, 1);
     oled.print("   ");        // clear offset on line 2
     oled.cursorMove(2, 1);
     oled.print(offset);       // Display offset on line 2
     DACreg = ((refVal<<4) * 0.8192) + offset;
    }
    else {
      DACreg = ((refVal<<4) * 0.8192);
    }

    // Now write the 16-bit value out to the DAC
    digitalWrite(DACSS, LOW);
    SPI.transfer((uint8_t) 0);
    SPI.transfer((uint8_t)((DACreg>>8) & 0xFF));
    SPI.transfer((uint8_t)(DACreg & 0xFF));
    digitalWrite(DACSS, HIGH);

    
    
  // *****-----*****-----*****-----*****
    // Print calculated output voltage from Teensy analog input A0
    // Check if output voltage is out of tolerance based on
    // errorvoltage variable and set status LED violet if out
    // of tolerance. The Teensy ADC is not as accurate as precision
    // DAC so this is only a check (~ +/- 0.5%)errorvoltage setting. 
    // Error status must be reset by switching to a mode! or using
    // the front pannel Mode reset switch
    
    delay(75);          // Let the output settle before reading
    average = 0.0000;   // A0 input averaging
      for (int i=0; i < 64; i++) {
        average = average + analogRead(analog0);
      }
    code = average/64;
    
    // include Teensy A-D error correction variables, Set for each Teensy
    Serial1.print(" Output voltage = ");
    Serial1.print((code * 0.0003057)-0.0026, 4);  //0.0003051 0.000 base value
    Serial1.print(" +/- ");
    Serial1.print((errorvoltage-1), 0);
    Serial1.print(" mV ");
    Serial1.println(refVal);

    oled.cursorMove(1, 7);
    oled.print((code * 0.0003057)-0.0026, 3);
    
    if ((refVal - ((code * 0.3057)-2.6)) > errorvoltage) {
      LEDcolor(violet);               //0.3051 base value
    }
    if ((((code * 0.3057)-2.6) - refVal) > errorvoltage) {
      LEDcolor(violet);               //0.3051 base value
    }
  // *****-----*****-----*****-----*****
    
    newVal = false;  // set the flag to false again after updating the DAC
  }
  
  // Convert the binary reference value into decimal digits for display

  num = refVal;
  oled.cursorMove(1, 1);
    oled.print((num / 1000), 3);       // Set decimal point
}

//-=|=-=|=-=|=-=|=-=|=-=|=-=|=-=|=-=|=-=|=-=|=-=|=-=|=-=|=-=|=-=|
// Takes the data from the array and generates a new value for the Reference
boolean ParseCommand() {

  uint8_t i = 0;
  uint16_t j = 0;
  boolean retVal = false;

  if(CmdArray[5] != 10 && CmdArray[5] != 13) {
    // Error in the command array.  Clear it and start over.
    for(i=0;i<7;i++)CmdArray[i] = 0;
    CmdArrayIdx = 0;
    return false;
  }
  
  for(i=1;i<5;i++){
    j = j*10 + (CmdArray[i]-48); // '0'==48
  }
  if(j>MAXVAL) j = MAXVAL;
   Serial1.println(j);

  switch (CmdArray[0]) {
    case 33: // '!'
      mode = RAW;
      refVal = j;
      retVal = true;
      LEDcolor(red);
      oled.displayOn();
      oled.cursorMove(1, 13);
      oled.print("RAW");
      break;
    case 35: // '#'
      mode = CORRECTED;
      refVal = j;
      retVal = true;
      LEDcolor(blue);
      oled.displayOn();
      oled.cursorMove(1, 13);
      oled.print("COR");
      break;
    case 'W':
      if(mode == RAW) {
        eep.write(refVal, (byte)j);
        Serial1.print(refVal);  // Serial.print(refVal);
        Serial1.print(":");  // Serial.print(":");
        Serial1.println((byte)j);  // Serial.println((byte)j);
      }
      retVal = false;
      break;
    case 'U':
      offset = (byte)j;
      useFlag = true;
      retVal = true;
      LEDcolor(green);
      oled.cursorMove(1, 13);
      oled.print("UOS");
      break;
    case 'N':
      mode = CORRECTED;
      useFlag = false;
      retVal = true;
      LEDcolor(blue);
      oled.cursorMove(1, 13);
      oled.print("COR");
      break;
    case 'C':
      mode = RAW;
      retVal = true;
      LEDcolor(teal);
      oled.cursorMove(1, 13);
      oled.print("CAL");
      break;

    case 'O':
      mode = CORRECTED;
      refVal = j;
      retVal = true;
      LEDcolor(blue);
      oled.displayOff();
      break;
      
    case 'R':
      for(i=0;i<(MAXVAL+1);i++){
        Addr = i;
        Serial1.print((Addr), DEC);  // Serial.print memory address
        Serial1.print(":");  // Serial.print : seperator
        Serial1.println(eep.read(Addr), DEC);
        // delay(10);
      }
    default:
      retVal = false;
  }

  for(i=0;i<7;i++)CmdArray[i] = 0;
  CmdArrayIdx = 0;
  return retVal;
}

void LEDcolor(uint8_t color){     // Set the RGB Rotary LED color
  digitalWrite(blueled, ~(color >> 2) & 0x1);
  digitalWrite(greenled, ~(color >> 1) & 0x1);
  digitalWrite(redled, ~color & 0x1);
}

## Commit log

2022-03-27 Add files via upload
    Teensyduino sketch for the Programmable Voltage Reference (PVR) hardware version 3.14 and 3,18
2022-03-28 Update VoltageReferenceProgrammableTeensyOLEDrev300.ino
    Notes and Version update
2023-02-09 Update VoltageReferenceProgrammableTeensyOLEDrev300.ino
    Changed MAXVAL and MINVAL from uint32_t to int16_t integers to correct:
    warning: comparison between signed and unsigned integer expressions [-Wsign-compare]
    if (refVal > MAXVAL) refVal = 1;
    [VoltageReferenceProgrammableTeensyOLEDrev300.ino]

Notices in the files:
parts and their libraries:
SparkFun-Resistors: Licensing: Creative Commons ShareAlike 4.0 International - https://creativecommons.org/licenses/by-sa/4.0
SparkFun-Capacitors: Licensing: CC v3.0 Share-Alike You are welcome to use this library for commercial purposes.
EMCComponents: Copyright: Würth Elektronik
